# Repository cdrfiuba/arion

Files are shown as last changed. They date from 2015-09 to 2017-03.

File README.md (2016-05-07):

# Arión

Arión es un seguidor de líneas basado en la categoría Micromouse. Se caracteriza por ser tanto pequeño como liviano, y por estar siempre en búsqueda de innovaciones que le permitan tener mayor velocidad y mejor control, mediante diferentes mejoras de mecánica, electrónica y software. Nuestro objetivo es ganar las varias competencias de carreras que organiza la Liga Nacional de Robótica, mientras proporcionamos un diseño abierto y fácilmente replicable, para que cualquiera pueda hacer su propio robot y hacerle las modificaciones que potencien el estado de la robótica en nuestro país.

## Estado Actual

Un primer prototipo con varias adaptaciones obtuvo el tercer lugar en la Liga Nacional de Robótica de 2015. Actualmente estamos estandarizando estas adaptaciones para tener un diseño monolítico, tanto de mecánica y electrónica como de software.

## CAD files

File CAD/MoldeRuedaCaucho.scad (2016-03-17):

$fn = 40; // 360 es liso, para exportar

diametro_exterior = 30; // diámetro exterior de la rueda
ancho = 10; // ancho de la rueda
espesor = 5; // espesor buscado de la rueda (radio exterior - radio interior)

diametro_tornillo = 5; // diámetro de tornillo

espesor_pared_exterior = 4; // tamaño de la paredcita exterior
espesor_piso = 5; // espesor de la base del molde

radio_rueda = diametro_exterior / 2;
radio_tornillo = diametro_tornillo / 2;

// este translate mueve el borde de la pieza al punto [0, 0]
translate([radio_rueda + espesor_pared_exterior, radio_rueda + espesor_pared_exterior, 0])
difference() {
  union() {
    // pieza base contenedora
    difference() {
      // base y paredes del molde
      color("pink")    cylinder(h=(ancho + espesor_piso), r=(radio_rueda + espesor_pared_exterior));
      // hueco para el tornillo central
      color("SkyBlue") cylinder(h=(espesor_piso), r=(radio_tornillo));
      // espacio para la cubierta (esto es lo que se llenará de caucho)
      translate([0, 0, espesor_piso]) color("SkyBlue") cylinder(h=(ancho), r=(radio_rueda));
    }

    // pieza móvil del centro
    translate([diametro_exterior, 0, -espesor_piso]) // esto saca la pieza de adentro de la otra
    translate([0, 0, espesor_piso]) // pone la pieza central justo arriba de la otra
    difference() {
      // pieza central para determinar el espesor de la rueda
      color("pink")    cylinder(h=ancho, r=(radio_rueda - espesor));
      // hueco adicional central para no requerir un tornillo muy largo
      translate([0, 0, espesor_piso]) color("SkyBlue") cylinder(h=ancho, r=(radio_rueda - espesor - espesor_pared_exterior));
      // tornillo central
      color("SkyBlue") cylinder(h=ancho, r=(radio_tornillo));
    }
  }
  // corte transversal:
  // primero hay que deshacer el translate, y luego aplicar un cubo de diferencia
  //translate([-(radio_rueda + espesor_pared_exterior), -(radio_rueda + espesor_pared_exterior), 0])
  //  color("LightYellow") cube([diametro_exterior * 2, radio_rueda + espesor_pared_exterior, ancho + espesor_piso]);
}

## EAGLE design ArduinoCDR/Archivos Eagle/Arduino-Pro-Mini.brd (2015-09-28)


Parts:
C1, C2, C3, C10: 0.1uF; 0603-CAP
C13, C19: 10uF; EIA3216
D3: Green; 0603-LED-ALT1
FRAME1: FRAME-LETTER; CREATIVE_COMMONS
JP1: FTDI Basic; 1X06
JP2, JP3: M02PTH; 1X02
JP5, JP8: FIDUCIALUFIDUCIAL; MICRO-FIDUCIAL
JP6, JP7: M12PTH; 1X12
LED1: Red; 0603-LED-ALT1
Q1: 8/16/20MHz; RESONATOR-SMD-1:1
R1, R3: RESISTOR0603-RES; 0603-RES
R2, R11: 10K; 0603-RES
R6: 330; 0603-RES
S1: Reset; TACTILE-SWITCH-SMD-ALT01
SJ1: SOLDERJUMPERNC; SJ_2S
U1: ATMEGA328; TQFP32-08
U2: MIC5205; SOT23-5
U$1: LOGO-SFESK; SFE-LOGO-FLAME
U$3: OSHW-LOGOS; OSHW-LOGO-S
U$11: LOGO-SFENEW; SFE-NEW-WEBLOGO

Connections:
A0: JP6.8, U1.23 (PC0(ADC0))
A1: JP6.7, U1.24 (PC1(ADC1))
A2: JP6.6, U1.25 (PC2(ADC2))
A3: JP6.5, U1.26 (PC3(ADC3))
A4: JP2.1, R1.1, U1.27 (PC4(ADC4/SDA))
A5: JP2.2, R3.1, U1.28 (PC5(ADC5/SCL))
A6: JP3.1, U1.19 (ADC6)
A7: JP3.2, U1.22 (ADC7)
AREF: C1.2, U1.20 (AREF)
D2: JP7.8, U1.32 (PD2(INT0))
D3: JP7.7, U1.1 (PD3(INT1))
D4: JP7.6, U1.2 (PD4(XCK/T0))
D5: JP7.5, U1.9 (PD5(T1))
D6: JP7.4, U1.10 (PD6(AIN0))
D7: JP7.3, U1.11 (PD7(AIN1))
D8: JP7.2, U1.12 (PB0(ICP))
D9: JP7.1, U1.13 (PB1(OC1A))
D10: JP6.12, U1.14 (PB2(SS/OC1B))
DTR: C2.2, JP1.1 (DTR)
GND: C1.1, C3.1, C10.2, C13.C (-), C19.C (-), D3.C, JP1.5 (CTS), JP1.6 (GND), JP6.2, JP7.9, Q1.2, R11.1, S1.1, S1.2 (1), U1.3 (GND), U1.5 (AGND), U1.21 (GND), U2.2 (GND)
MISO: JP6.10, U1.16 (PB4(MISO))
MOSI: JP6.11, U1.15 (PB3(MOSI/OC2))
unnamed: Q1.3, U1.8 (PB7(XTAL2/TOSC2))
unnamed: Q1.1, U1.7 (PB6(XTAL1/TOSC1))
unnamed: LED1.A, SJ1.1, U2.5 (OUT)
unnamed: LED1.C, R11.2
unnamed: D3.A, R6.2
RAW: C19.A (+), JP6.1, U2.1 (IN), U2.3 (EN)
RESET: C2.1, JP6.3, JP7.10, R2.1, S1.3 (2), S1.4 (2), U1.29 (PC6(/RESET))
RXI: JP1.3 (TXO), JP7.11, U1.30 (PD0(RXD))
SCK: JP6.9, R6.1, U1.17 (PB5(SCK))
TXO: JP1.2 (RXI), JP7.12, U1.31 (PD1(TXD))
VCC: C3.2, C10.1, C13.A (+), JP1.4 (VCC), JP6.4, R1.2, R2.2, R3.2, SJ1.2, U1.4 (VCC), U1.6 (VCC), U1.18 (AVCC)

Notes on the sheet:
Original Arduino Mini Design by Team Arduino
Arduino Pro Mini Design by Spark Fun Electronics
Max Voltage Input: 16VDC
Max Current Output: 150mA
Board is marked with combination of
resonator frequency and regulator voltage.
VCC = 5V or 3.3V Output
Optional Pullups for I2C lines
Off Grid Breakout headers
Power isolation jumper
(for low power aplications)

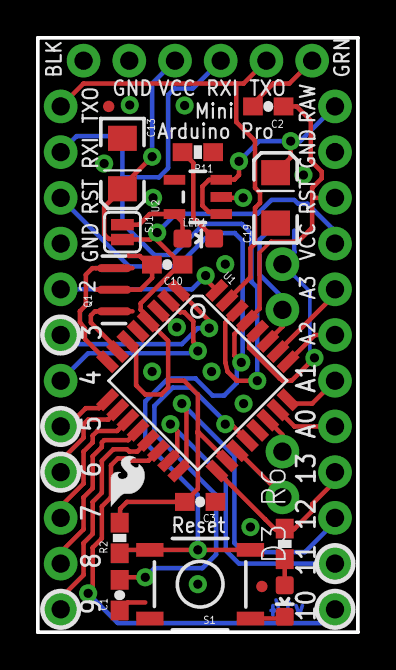
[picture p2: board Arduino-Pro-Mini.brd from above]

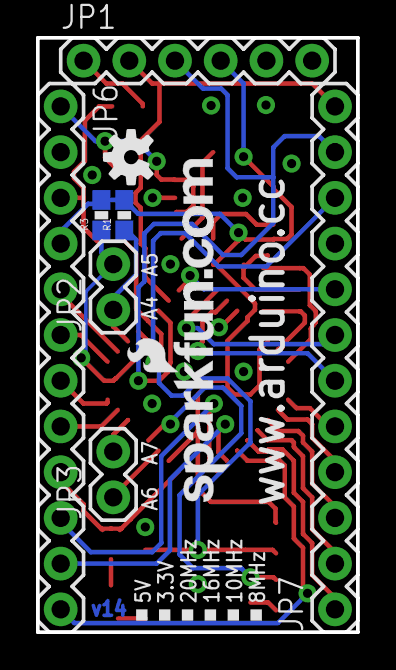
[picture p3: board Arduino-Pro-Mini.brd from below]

Board: 2 copper layers, 17.8 x 33.0 mm, 29 parts (9 on the bottom side), 33 nets.

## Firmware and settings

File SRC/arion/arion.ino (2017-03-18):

#include <avr/io.h>
//#include <avr/interrupt.h>
#include <EEPROM.h>

/** inicio de parámetros configurables **/

// parámetro para mostrar información por puerto serie en el ciclo principal
// const bool DEBUG = false;
const bool DEBUG = false;

// parámetros de velocidades máximas en recta y curva
int rangoVelocidadRecta = 120; // velocidad real = rango - freno / 2
int rangoVelocidadRectaLenta = 90; // velocidad real = rango - freno / 2
int rangoVelocidadCurva = 80;
int rangoVelocidadAfuera = 30;

// velocidad permitida en reversa al aplicar reduccionVelocidad en PID
int velocidadFrenoRecta = 70;
int velocidadFrenoRectaLenta = 70;
int velocidadFrenoCurva = 0;
int velocidadFrenoAfuera = 0;

// parámetros PID
float kPRecta = 0.03;
float kDRecta = 5.0;
float kPRectaLenta = 0.03;
float kDRectaLenta = 5.0;
float kPCurva = 0.12;
float kDCurva = 3.0;
//const float kI = 1.0 / 2500.0;

// parámetro para reducir a 0 rangoVelocidad cuando se entra en una curva,
// para frenar de forma controlada
const int tiempoFrenoInicioCurva = 300; //ms

// parámetros encoders
const int cantidadDeSegmentos = 1;
// Arrays donde se guardan las distancias medidas por los encoders
unsigned int distanciasRuedaIzquierda[cantidadDeSegmentos] = {};
unsigned int distanciasRuedaDerecha[cantidadDeSegmentos] = {};
const int aprenderDistancias = 0;
const int usarDistancias = 1;
const int ignorarDistancias = 2;
// determina si se graban los valores en la EEPROM, si se usan para controlar
// la velocidad de recta y curva, o si se ignoran
const int modoUsoDistancias = ignorarDistancias;
const int cantidadDeVueltasADar = 1; // en aprendizaje, se frena al terminar
const int distanciaAnticipoCurva = 300; // medido en cuentas de encoder
bool usarCarrilIzquierdo = false;

// parámetros para usar velocidades distintas en cada recta y en cada curva, 
// de cada carril (izq o der) y parámetros para pasar a una velocidad menor 
// después de cierto tiempo en la recta, según el tramo 
// (nota: se puede agregar una recta más para contemplar la última recta, que 
// si bien es la misma en la que se arranca, puede tener hardcodeado la 
// velocidad máxima, pues no es importante si se cae inmediatamente después de 
// terminar esa recta)
const bool usarTiemposPorRecta = false;
const int cantidadDeRectas = 10; // asume que empieza en recta
const int d1 = 130, d2 = 200, dp = 400, dt = 400; // dn = n maderas de largo
const unsigned int tiempoAMaxVelocidadRecta[cantidadDeRectas] = {
  //d1, d1
  d2, d1, d1, d2, dt, d2, d1, dp, d1, d1
  //65000
};
const bool usarVelocidadPorCurva = false;
const int C = rangoVelocidadCurva;
const int velocidadesCurvaCI[cantidadDeRectas] = {C+00, C+00};
const int velocidadesCurvaCD[cantidadDeRectas] = {};

// parámetros para modo curva
const bool MODO_CURVA_INICIAL = false; // para debuggear si arranca en modo curva o no
const int TOLERANCIA_SENSOR_CURVA = 450; // más de 1024 hace que se ignoren los sensores curva
const int DEBOUNCE_MODO_CURVA = 200; // ms, entre cambios de modo curva
const int tiempoDebounceModoCurva = 100; // ms, entre sensor curva izq y sensor curva der

// parámetros de sensoresLinea cuando estadoActualAdentro == false
const int MINIMO_SENSORES_LINEA = 2000;
const int MAXIMO_SENSORES_LINEA = 4000;

// parámetro medido por tiempoUs para compensar tiempo transcurrido
// entre ciclo y ciclo del PID
const int tiempoCicloReferencia = 1040;//390;

// parámetro batería
// 8.23 V => 847
// 8.00 V => 822
// 8.27 V => 848
// 7.71 v => 791
// 7.50 V => 771 // armado con regla de 3
const int MINIMO_VALOR_BATERIA = 760;
int minimoValorBateria = MINIMO_VALOR_BATERIA; // permite modificarlo en caso de emergencia
const int MAXIMO_VALOR_BATERIA = 859; // = 8.4V / 2 (divisor resistivo) * 1023.0 / 5V

// parámetros para promedio ponderado de sensoresLinea
const int COEFICIENTE_SENSOR_IZQ     = 0;
const int COEFICIENTE_SENSOR_CEN_IZQ = 2000;
const int COEFICIENTE_SENSOR_CEN     = 3000;
const int COEFICIENTE_SENSOR_CEN_DER = 4000;
const int COEFICIENTE_SENSOR_DER     = 6000;
// centro de línea para sensoresLinea
const int centroDeLinea = 3000;

// parámetros para estadoActualAdentro,
// determina si se debe clampear los valores de sensoresLinea en el PID
const int tolerancia = 50; // margen de ruido al medir negro
const int toleranciaBorde = 500; // valor a partir del cual decimos que estamos casi afuera

// parámetro para usar ADC asíncrono, mediante interrupciones
const bool usarInterrupcionesADC = true;

/** fin de parámetros configurables **/


// definición de pines del micro. para Arión 2016 LNR
const int pwmMotorD = 9; // OC1A
const int pwmMotorI = 10; // OC1B
const int sentidoMotorD = 5;
const int sentidoMotorI = 6;
const int led1 = 12;  // Led 1
const int led2 = 13;  // Led 2
const int led3 = 11;  // Led 3
const int boton1 = 8; // Boton1(pcb)   boton3 (code): Calibrar
const int boton2 = 7; // pin 1 arduino  - pin 31(avr)
const int boton3 = 7; // Boton2(pcb)   boton1 (code): Arrancar
const int sensor0 = A0; // sensor0 (code)   sensor2(pcb) izquierda  [izq]
const int sensor1 = A1; // cenIzq           sensor3(pcb)
const int sensor2 = A2; // cen              sensor4(pcb)
const int sensor3 = A3; // cenDer           sensor5(pcb)
const int sensor4 = A4; // der              sensor6(pcb)
const int batteryControl = A6; // 
const int sensorCurvaIzq = A7; //           sensor1(pcb)
const int sensorCurvaDer = A5; //           sensor7(pcb)
const int habilitador = 4; // PD4

// armado de array de sensores y arrays para calibración
const int cantidadDeSensores = 7;
int sensoresSinCalibrar[cantidadDeSensores];
int sensores[cantidadDeSensores];
 // guarda los valores mínimos y máximos usados al calibrar
int minimosSensores[cantidadDeSensores];
int maximosSensores[cantidadDeSensores];
float coeficientesSensores[cantidadDeSensores];
byte canalesADC[cantidadDeSensores] = {
  sensor0, sensor1, sensor2, sensor3, sensor4, sensorCurvaIzq, sensorCurvaDer
};
volatile byte indiceConversion = 0;

// indices de array sensores
const int izq      = 0;
const int cenIzq   = 1;
const int cen      = 2;
const int cenDer   = 3;
const int der      = 4;
const int curvaIzq = 5;
const int curvaDer = 6;

// control para inicializar la calibración de los sensores
// sólo cuando se prende el robot
bool inicializarCalibracionInicial = true;

// dirección motor
const int atras = LOW;
const int adelante = HIGH;

// dirección de direccionMovimientoLateral
const int haciaDerecha = 1;
const int haciaIzquierda = 0;

// bordes de ultimoBorde para modo "me fui"
const int derecha = 1;
const int izquierda = 0;

// contadores de encoders
volatile unsigned int contadorMotorIzquierdo = 0;
volatile unsigned int contadorMotorDerecho = 0;

// macro y string de debug por puerto serie
char debug_string_buffer[30];
#define debug(formato, valor) \
  sprintf(debug_string_buffer, formato, valor); \
  Serial.print(debug_string_buffer);

#define clearBit(sfr, bit) (_SFR_BYTE(sfr) &= ~_BV(bit))
#define setBit(sfr, bit)   (_SFR_BYTE(sfr) |=  _BV(bit))
#define EEPROM_LENGTH 1024 // el ATmega328 tiene 1KB de EEPROM

#define led1On() digitalWrite(led1, LOW)
#define led2On() digitalWrite(led2, LOW)
#define led3On() digitalWrite(led3, LOW)
#define led1Off() digitalWrite(led1, HIGH)
#define led2Off() digitalWrite(led2, HIGH)
#define led3Off() digitalWrite(led3, HIGH)

#define detenerInterrupcionesADC() clearBit(ADCSRA, ADIE)
#define iniciarInterrupcionesADC() ADCSRA |= (1 << ADIE) | (1 << ADSC)

#define SERIAL_BPS 2000000

void setup() {
  // como los motores se manejan con AnalogWrite,
  // no hace falta ponerlos como salida
  // pinMode(pwmMotorD, OUTPUT);
  // pinMode(pwmMotorI, OUTPUT);

  pinMode(sentidoMotorD, OUTPUT);
  pinMode(sentidoMotorI, OUTPUT);

  // como los sensores y el batteryControl se leen con AnalogRead,
  // no hace falta ponerlos como entrada
  //pinMode(sensor0, INPUT);
  //pinMode(sensor1, INPUT);
  //pinMode(sensor2, INPUT);
  //pinMode(sensor3, INPUT);
  //pinMode(sensor4, INPUT);
  //pinMode(batteryControl, INPUT);
  //pinMode(sensorCurvaIzq, INPUT);
  //pinMode(sensorCurvaDer, INPUT);

  // saco los input buffer de los pines que leo por ADC
  setBit(DIDR0, ADC5D);
  setBit(DIDR0, ADC4D);
  setBit(DIDR0, ADC3D);
  setBit(DIDR0, ADC2D);
  setBit(DIDR0, ADC1D);
  setBit(DIDR0, ADC0D);

  pinMode(led1, OUTPUT);
  pinMode(led2, OUTPUT);
  pinMode(led3, OUTPUT);
  pinMode(habilitador, OUTPUT);

  pinMode(boton1, INPUT);
  pinMode(boton2, INPUT);
  pinMode(boton3, INPUT);

  Serial.begin(SERIAL_BPS);

  // pone el prescaler del ADC Clock en 16
  // esto reduce el tiempo de cada conversión AD de ~112us a ~20us
  //setBit(ADCSRA, ADPS2);
  //clearBit(ADCSRA, ADPS1);
  //clearBit(ADCSRA, ADPS0);

  // habilita interrupciones globales
  // NOTA: Arduino deshabilita y habilita interrupciones cuando quiere leer
  // los valores de millis() y micros().
  sei();

  // Configuración de encoders
  // Para poder leer encoders con las interrupciones de Pin Change
  // (que no son externas) y distinguir las dos interrupciones,
  // tienen que estar en grupos distintos de PCIE0, PCIE1 y PCIE2.
  // Actualmente está configurado INT0 (externa) y PCINT22 (pin change)

  // configura INT0 (pin digital 2) en logical change
  // EICRA determina el modo de disparo de la interrupción
  // (en EIFR cambia el bit INTF0 cuando se dispara la interrupción)
  //clearBit(EICRA, ISC01);
  //setBit(EICRA, ISC00);
  //setBit(EIMSK, INT0);
  // alternativamente se lo puede configurar como PCINT, usando
  // PCINT18 en PCIE2 y PCMSK2
  // setBit(PCICR, PCIE2);
  // setBit(PCMSK2, PCINT18);

  // configura PCINT22 (pin digital 6), del grupo PCINT2
  // (en PCIFR cambia el bit PCIF2 cuando se dispara la interrupción)
  //setBit(PCICR, PCIE2);
  //setBit(PCMSK2, PCINT22);

  if (inicializarCalibracionInicial) {
    for (int i = 0; i < cantidadDeSensores; i++) {
      sensoresSinCalibrar[i] = 0;
      sensores[i] = 0;
      minimosSensores[i] = 0;
      maximosSensores[i] = 1023;
      coeficientesSensores[i] = 1.0;
    }
    inicializarCalibracionInicial = false;
  }
  leerCalibracionDeEEPROM();

  digitalWrite(habilitador, HIGH);
  led1Off();
  led2Off();
  led3Off();
  apagarMotores();

  // Cambia la frecuencia de PWM, cambiando el prescaler del Timer1 
  // El default es 0b011 (64) en Phase Correct, ~490Hz
  // 0b011 prescaler 64 --> 490 Hz / 976 Hz
  //clearBit(TCCR1B, CS12);
  //setBit(TCCR1B, CS11);
  //setBit(TCCR1B, CS10);
  
  // Fast PWM 8-bit (TOP=0x00FF): WGM1[3:0] = 0b0101
  //clearBit(TCCR1B, WGM13);
  //setBit(TCCR1B, WGM12);
  //clearBit(TCCR1A, WGM11);
  //setBit(TCCR1A, WGM10);
  
  // reseteo el valor del encoder
  contadorMotorIzquierdo = 0;
  contadorMotorDerecho = 0;

  // pone en marcha las mediciones continuas de los AD
  if (usarInterrupcionesADC) {
    iniciarConversiones();
  }

}

bool apretado(int boton) {
  return (digitalRead(boton) == LOW);
}

void esperarReboteBoton() {
  delay(5);
}

inline void obtenerSensores() {
  // este procedimiento no se usa cuando las conversiones AD se hacen
  // mediante interrupciones
  if (usarInterrupcionesADC) return;
  // carga en el array de sensores las lecturas AD de cada sensor
  // este proceso lleva 112us con el ADC con prescaler 16
  sensoresSinCalibrar[izq]      = 1024 - analogRead(sensor0);
  sensoresSinCalibrar[cenIzq]   = 1024 - analogRead(sensor1);
  sensoresSinCalibrar[cen]      = 1024 - analogRead(sensor2);
  sensoresSinCalibrar[cenDer]   = 1024 - analogRead(sensor3);
  sensoresSinCalibrar[der]      = 1024 - analogRead(sensor4);
  sensoresSinCalibrar[curvaIzq] = 1024 - analogRead(sensorCurvaIzq);
  sensoresSinCalibrar[curvaDer] = 1024 - analogRead(sensorCurvaDer);
}

inline void obtenerSensoresCalibrados() {
  int valor = 0;
  obtenerSensores();
  for (int i = 0; i < cantidadDeSensores; i++) {
    valor = (sensoresSinCalibrar[i] - minimosSensores[i]);
    valor = valor * coeficientesSensores[i];
    if (valor > 1023) {
      valor = 1023;
    } else if (valor < 0) {
      valor = 0;
    }
    sensores[i] = (int)valor;
  }
}

void calibrarSensores() {
  // leo los sensores, y guardo los mínimos y los máximos
  obtenerSensores();
  for (int i = 0; i < cantidadDeSensores; i++) {
    if (sensoresSinCalibrar[i] < minimosSensores[i]) {
      minimosSensores[i] = sensoresSinCalibrar[i];
    }
    if (sensoresSinCalibrar[i] > maximosSensores[i]) {
      maximosSensores[i] = sensoresSinCalibrar[i];
    }
    coeficientesSensores[i] = 1023.0 / (float)(maximosSensores[i] - minimosSensores[i]);
  }
}

void mostrarSensorLEDs(int sensor) {
  if (sensor >= cantidadDeSensores || sensor < 0) {
    return;
  }
  digitalWrite(led1, ((sensores[sensor] / 768) ? HIGH : LOW));
  digitalWrite(led2, ((sensores[sensor] / 512) ? HIGH : LOW));
  digitalWrite(led3, ((sensores[sensor] / 256) ? HIGH : LOW));
}

void mostrarSensoresPorSerie() {
  debug("%.3d ", analogRead(batteryControl));
  debug("%.4d ", sensores[izq]);
  debug("%.4d ", sensores[cenIzq]);
  debug("%.4d ", sensores[cen]);
  debug("%.4d ", sensores[cenDer]);
  debug("%.4d ", sensores[der]);
  debug("%.4d ", sensores[curvaIzq]);
  debug("%.4d ", sensores[curvaDer]);
  if (modoUsoDistancias != ignorarDistancias) {
    debug("%.4d ", contadorMotorIzquierdo);
    debug("%.4d ", contadorMotorDerecho);
  }
  if (modoUsoDistancias == usarDistancias) {
    debug("%s ", "|");
    for (int i = 0; i < cantidadDeSegmentos; i++) {
      debug("{%d, ", distanciasRuedaIzquierda[i]);
      debug("%d} ", distanciasRuedaDerecha[i]);
    }
  }
  debug("%s", "\n");
}

void apagarMotores() {
  digitalWrite(sentidoMotorI, adelante);
  digitalWrite(sentidoMotorD, adelante);
  analogWrite(pwmMotorI, 255 - 0);
  analogWrite(pwmMotorD, 255 - 0);
}
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
void loop() {
  // definición de variables locales
  float errP = 0;
  float errPAnterior = 0;
  //float errI = 0;
  float errD = 0;
  float kP = 1;
  float kD = 0;
  int rangoVelocidad;
  int velocidadFreno;
  int reduccionVelocidad;
  int velocidadMotorFrenado;
  int direccionMovimientoLateral;
  int sensoresLinea = 0;
  bool estadoActualAdentro = true;
  int sensorCurvaIzqActivo;
  int sensorCurvaDerActivo;
  bool calibracionReseteada = false;
  int ultimoBorde = izquierda;
  bool modoCurva = MODO_CURVA_INICIAL;
  // para calcular tiempo entre ciclos de PID.
  int tiempoUs = tiempoCicloReferencia; // no debe ser 0, pues se usa para dividir
  unsigned long int ultimoTiempoUs = 0; // guarda el valor de micros()
  unsigned long int ultimoTiempoRecta = 0; // guarda el valor de millis()
  unsigned long int ultimoTiempoCurva = 0; // guarda el valor de millis()
  unsigned long int ultimoTiempoModoCurva = 0; // guarda el valor de millis()
  int contadorRecta = 0;
  int velocidadesCurvaPorTramo[cantidadDeRectas];
  int indiceSegmento = 0; // almacena el indice de segmento de la pista
  int distanciaActual = 0;
  int distanciaEsperada = 0;
  int cantidadDeVueltasRestantes = cantidadDeVueltasADar;
  bool cambioModoCurvaCompletado = true;
  byte contadorDataSerie = 0;
  unsigned long int ultimoTiempoSensorCurvaIzq = 0; // guarda el valor de millis()
  unsigned long int ultimoTiempoSensorCurvaDer = 0; // guarda el valor de millis()

  // si fue seleccionado el modo usarVelocidadPorCurva,
  // precargo la data del carril seleccionado
  if (usarVelocidadPorCurva) {
    if (usarCarrilIzquierdo) {
      for (int i = 0; i < cantidadDeRectas; i++) {
        velocidadesCurvaPorTramo[i] = velocidadesCurvaCI[i];
      }
    } else {
      for (int i = 0; i < cantidadDeRectas; i++) {
        velocidadesCurvaPorTramo[i] = velocidadesCurvaCD[i];
      }
    }
  }

  // inicialización de todas las cosas
  setup();

  // hasta que se presione el botón, espera
  while (!apretado(boton1)) {
    leerVariablesDeSerie();
    
    // deshabilito temporalmente las interrupciones para poder hacer lecturas
    // manuales con AnalogRead de la batería
    detenerInterrupcionesADC();
    delayMicroseconds(120); // espero a que termine la última conversión

    chequearBateriaBloqueante();
    obtenerSensoresCalibrados();
    mostrarSensoresPorSerie();

    // le doy tiempo a las interrupciones ADC
    // a refrescar el valor de los sensores
    iniciarInterrupcionesADC();
    delay(1);

    // carga opcional de información de encoders,
    // que depende del carril actual
    if (modoUsoDistancias == usarDistancias) {
      leerDistanciasDeEEPROM();
    }

    // muestra estado de encoders
    if (usarCarrilIzquierdo) {
      led1On();
      led2Off();
    } else {
      led1Off();
      led2On();
    }

    // calibración usando el botón
    calibracionReseteada = false;
    while (apretado(boton3)) {
      if (!calibracionReseteada) {
        // reseteo la calibración
        for (int i = 0; i < cantidadDeSensores; i++) {
          minimosSensores[i] = 1023;
          maximosSensores[i] = 0;
        }
        calibracionReseteada = true;
        
        // reuso la bandera de calibracionReseteada para que esto se ejecute
        // una sola vez por apretada de botón
        usarCarrilIzquierdo = !usarCarrilIzquierdo;
      }

      led1On();
      calibrarSensores();
      led1Off();
      led2Off();
      led3Off();
      delay(50);
    }
    if (calibracionReseteada) {
      guardarCalibracionEnEEPROM();
    }

  }
  esperarReboteBoton();
  led1Off();
  led2Off();
  led3Off();

  // hasta que se suelte el botón, espera
  while (apretado(boton1));
  esperarReboteBoton();

  // seteo de rangoVelocidad para arranque gradual
  if (modoCurva) {
    rangoVelocidad = rangoVelocidadCurva;
  } else {
    rangoVelocidad = rangoVelocidadRecta;
  }

  // arranque gradual
  for (int i = 0; i < rangoVelocidad / 10; i++) {
    analogWrite(pwmMotorD, 255 - i * 10);
    analogWrite(pwmMotorI, 255 - i * 10);
    delay(10);
  }

  // inicialización tiempos
  ultimoTiempoRecta = millis();
  ultimoTiempoCurva = millis();
  ultimoTiempoUs = micros();
  ultimoTiempoSensorCurvaIzq = millis();
  ultimoTiempoSensorCurvaDer = millis();

  // ejecuta el ciclo principal hasta que se presione el botón
  while (!apretado(boton1)) {

    //chequearBateria();
    obtenerSensoresCalibrados();

    if (sensores[izq] > toleranciaBorde) {
      ultimoBorde = izquierda;
    } else if (sensores[der] > toleranciaBorde) {
      ultimoBorde = derecha;
    }

    // si me fui, entro en modo "corrección máxima"
      estadoActualAdentro = true;
    if (sensores[cenIzq] < tolerancia &&
        sensores[cen]    < tolerancia &&
        sensores[cenDer] < tolerancia) {
      if ( (sensores[izq] < tolerancia && sensores[der] < toleranciaBorde) ||
           (sensores[izq] < toleranciaBorde && sensores[der] < tolerancia) ) {
        estadoActualAdentro = false;
      }
    }

    // 50 microsegundos
    // modo pid
    // linea = (0 * s0 + 1000 * s1 + 2000 * s2 + 3000 * s3 + 4000 * s4) / (s0 + s1 + s2 + s3 + s4)
    sensoresLinea = (
      (long)sensores[izq]    * COEFICIENTE_SENSOR_IZQ +
      (long)sensores[cenIzq] * COEFICIENTE_SENSOR_CEN_IZQ +
      (long)sensores[cen]    * COEFICIENTE_SENSOR_CEN +
      (long)sensores[cenDer] * COEFICIENTE_SENSOR_CEN_DER +
      (long)sensores[der]    * COEFICIENTE_SENSOR_DER
    ) / (
      (long)sensores[izq]    +
      (long)sensores[cenIzq] +
      (long)sensores[cen]    +
      (long)sensores[cenDer] +
      (long)sensores[der]
    );

    // clampea valor extremo para indicarle al PID
    // que corrija con toda su fuerza
    if (estadoActualAdentro == false) {
      if (ultimoBorde == izquierda) {
        sensoresLinea = MINIMO_SENSORES_LINEA;
      } else {
        sensoresLinea = MAXIMO_SENSORES_LINEA;
      }
    }

    sensorCurvaIzqActivo = ((sensores[curvaIzq] > TOLERANCIA_SENSOR_CURVA) ? 1 : 0);
    sensorCurvaDerActivo = ((sensores[curvaDer] > TOLERANCIA_SENSOR_CURVA) ? 1 : 0);

    if (sensorCurvaIzqActivo == 0 && sensorCurvaDerActivo == 0) {
      cambioModoCurvaCompletado = false;
    }
    
    // cambio a modo curva si pasaron entre 0 y N milisegundos entre haber 
    // visto 1 en un sensor y el otro
    if (sensorCurvaIzqActivo == 1) {
      ultimoTiempoSensorCurvaIzq = millis();
      if (millis() - ultimoTiempoSensorCurvaDer < tiempoDebounceModoCurva) {
        cambioModoCurvaCompletado = true;
      }
    }
    if (sensorCurvaDerActivo == 1) {
      ultimoTiempoSensorCurvaDer = millis();
      if (millis() - ultimoTiempoSensorCurvaIzq < tiempoDebounceModoCurva) {
        cambioModoCurvaCompletado = true;
      }
    }

    if (cambioModoCurvaCompletado && millis() - ultimoTiempoModoCurva > DEBOUNCE_MODO_CURVA) {
      cambioModoCurvaCompletado = false;
      // tengo seguridad de que pasó el rebote del sensor
      modoCurva = !modoCurva;

      if (modoUsoDistancias == aprenderDistancias) {
        distanciasRuedaIzquierda[indiceSegmento] = contadorMotorIzquierdo;
        distanciasRuedaDerecha[indiceSegmento] = contadorMotorDerecho;
      }

      // indice usado para identificar el segmento
      indiceSegmento = (indiceSegmento + 1) % cantidadDeSegmentos;

      // Reseteo el valor del encoder
      contadorMotorIzquierdo = 0;
      contadorMotorDerecho = 0;

      // en el modo aprender, se apaga cuando termina la cantidad de vueltas
      if (modoUsoDistancias == aprenderDistancias) {
        if (indiceSegmento == 0) {
          cantidadDeVueltasRestantes--;
          if (cantidadDeVueltasRestantes <= 0) {
            apagarMotores();
            guardarDistanciasEnEEPROM();
            break;
          }
        }
      }

      ultimoTiempoModoCurva = millis();
      
      // si paso a modo curva, freno porque venia rápido
      if (modoCurva) {
        ultimoTiempoCurva = millis();
      } else {
        ultimoTiempoRecta = millis();
        contadorRecta++;
        if (contadorRecta == cantidadDeRectas) {
          contadorRecta = 0;
        }
      }
    }
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

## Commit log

2015-07-02 Commit inicial de la placa
    [arion.kicad_pcb, arion.sch]
2015-07-04 Inicio del codigo de seguimineto de pista de Arión
2015-07-09 Terminado de adaptar PID de Tito, con algunas mejoras. Emprolijamiento general. Se acomodaron declaraciones, se quitaron números mágicos, y otros ajustes.
2015-07-13 Quitados los casteos explícitos a int32_t en el ciclo de PID.
2015-08-04 Cambios en el codigo. Base de tiempo en us
2015-08-04 Se cambiaron los errores que habia en la ultima version
    [arion.kicad_pcb, arion.sch]
2015-08-12 Mejorado debug. Invertidos sensores para usar con pista blanca. Agregadas conversiones a Long. Temporalmente deshabilitados I y D del PID. Intercambiados botones 1 y 3.
2015-08-15 Codigo modificado para hacer pruebas
2015-08-15 Empezada calibración, hechas pruebas y mejoras en relación al uso del tiempo en el PID
2015-08-15 Primer codigo que se mueve sobre la linea sin caerse
2015-08-15 Casi que con esto me presento
2015-08-15 Me presento de cabeza
2015-08-15 40 de velocidad y funciona!
2015-08-15 45, con 5 de continua
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2015-08-22 Agregado freno al cambiar de velocidad en ciclo PID. Mejorada velocidad del robot.
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2015-09-22 Agrego archivos para el arduino pro mini propio
    [Arduino-Pro-Mini.brd, Arduino-Pro-Mini.sch, arduinopromini.kicad_pcb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]
2015-09-26 Agregado sensor Curva, con modo Curva para ir lento/rapido. Los valores no estan perfectos.
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2015-09-29 empezado clamp de sensores linea, nuevo modo afuera y valores de prueba
2015-10-01 Refactor. Movidas variables a loop(). Sacada calibración de setup(). Quitado parche sensorCurva.
2015-10-02 Agregado comentarios con los tiempos de procesamiento de los ciclos del programa
2015-10-03 prueba con sensor de curva en pista con rectas larga y curvas de 90 grados
2015-10-29 Optimizados sensado y calibración. Agregada velocidad por tramos. Serial activado siempre que no se esté en ciclo PID.
2015-11-03 Float PID
    Conversión a float de errores y calibración de sensores
    [arion.ino]
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2015-11-07 Tuneados parámetros, agregado tiempo máx velocidad para rectas
2015-11-21 Downgrade de estabilidad (lento y estable)
    Base de velocidad para lograr estabilidad en la pista de Bahía Blanca.
2015-12-06 Agregado diseño para imprimir el molde de una rueda.
    [MoldeRuedaCaucho.scad]
2015-12-07 Ajustes diseño molde. Agregado STL.
    Agregadas paredes para evitar rebalse, sacado código prototipo.
    [MoldeRuedaCaucho.scad]
2016-01-23 Inicio de la version 2.0 de la placa
    [arion.kicad_pcb, arion.sch, placa.kicad_pcb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]
2016-02-20 Added files via upload
    Agrego archivo parametrizado para molde de silicona
    [Molde.parametrizado.scad]
2016-03-12 Empezado a parametrizar MoldeRuedaCaucho.
    [MoldeRuedaCaucho.scad]
2016-03-17 MoldeRuedaCaucho: diseño de 30x10x5.
    Simplificado un poco el código, quitadas las paredcitas.
    [MoldeRuedaCaucho.scad]
2016-03-17 MoldeRuedaCaucho: STLs de 30x15x5 y 30x10x5.
    Borrado viejo Molde.parametrizado.scad.
    [Molde.parametrizado.scad, MoldeRuedaCaucho.scad]
2016-08-16 Primera prueba de medicion de tramos por encoder
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2016-08-22 Corregidos typos, estilo, y editados comentarios.
    Cambiado cuánto cambia el mínimo de batería al apretar el botón.
2016-08-23 Avances con encoders.
    Implementado freno anticipado de curva, ajustados parámetros PID y
    velocidades, y agregado freno intenso durante principio de curva.
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2016-09-10 Params, pines, long a int. Calibración en EEPROM.
    Nuevos parámetros, puestos pines de leds y de botones, agregadas macros
    de leds (porque en este robot se prenden con LOW) y agregadas funciones
    para leer y escribir los mínimos y máximos de los sensores en EEPROM
    para almacenar el resultado de la calibración.
2016-09-13 Parámetros configurables por serie.
    Algunos parámetros ahora se pueden cambiar por serie, sin reprogramar.
    Las funciones de EEPROM todavía tenían alguna cosa long que debía ser
    int.
2016-09-20 Agregado Sensor Curva Derecho. Sacados encoders.
    Se repitió el código del sensor curva izquierdo para el derecho, pero
    habría que poner un debounce o margen para que la lectura no tenga que
    ser simultánea en ambos sensores para cambiar de modo.
    Se deshabilitaron las interrupciones de los encoders.
2016-09-20 Fix sensores curva. Autocalibración. Botones.
    Ahora funciona el cambio de modo curva.
    La calibración ahora es automática, girando sobre el lugar.
    Intercambiados botones para arrancar con el del medio.
    [arion.ino]
2016-09-24 Parámetros. Calibración. Freno post-curva.
    Rearmados parámetros.
    Calibración por EEPROM anda después de cambiar
    fuses.
    Agregado tiempo de freno al entrar en modo curva: rango velocidad pasa a
    ser 0 por el tiempo indicado por el nuevo parámetro.
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2016-10-15 ADC asíncrono. Pruebas serie.
    Lectura de sensores por ADC asíncrono contínuo. Hacks para poder usar modo DEBUG sin que lleve tanto tiempo.
    Cambiado el modo en el que se espera a que se cumple el tiempoCicloReferencia.
2016-10-21 Parámetros. Posible fix interrupciones ADC.
    Movidos, reajustados, y quitados varios parámetros.
    Separados arrays de sensores calibrados y sensores sin calibrar, para que ande igual en modo bloqueante como con interrupciones.
    Agregados y cambiados algunos comentarios.
    [arion.ino]
2016-10-22 Pruebas prescaler Timer1.
    Probado cambiar frecuencia del Timer1 de los motores, en 4KHz, en 32KHz, y en 64Hz.
    Revertido clamp de sensores para modo afuera.
    [arion.ino]
2016-10-22 Parámetros. Fix chequeo batería bloqueante.
    Estaban al revés los valores de los clamps de sensores línea.
    Agregadas macros para prender y apagar sólo las interrupciones de los
    ADC, para apagar las interrupciones globales, necesarias para el uso de
    delay().
    Probadas diferentes frecuencias de PWM.
    [arion.ino]
2016-11-05 Quitado coast de motores. Debounce sensores curva.
    Cambiado modo PWM para que los motores no hagan coast, y poder controlar
    mejor los motores yendo para adelante.
    Permitido delay entre sensores curva para que no tengan que estar ambos
    prendidos para cambiar de modo curva.
2017-03-18 Pruebas serie: ahora Serial anda a 2Mbps.
    Quitado input buffer a pines ADC mediante DIDR0.

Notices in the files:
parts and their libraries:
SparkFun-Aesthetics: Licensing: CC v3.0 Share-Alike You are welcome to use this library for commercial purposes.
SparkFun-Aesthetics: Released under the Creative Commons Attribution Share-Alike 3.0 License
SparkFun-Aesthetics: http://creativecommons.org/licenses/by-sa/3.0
